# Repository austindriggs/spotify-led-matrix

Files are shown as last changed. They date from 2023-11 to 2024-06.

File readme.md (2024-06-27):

# Welcome to my first project!

My name is Austin Driggs and I am an Electrical Engineering student at WVU.
Please check out my [LinkedIn](https://www.linkedin.com/in/austindriggs/)!

### Purpose

This project uses an ESP32 microcontroller to display my "Now Playing" songs from Spotify onto an LED matrix panel, along with some added features.

The purpose of this project is to of course learn some new technical skills, but to also practice things related to my career in open sourced coding/projects and project management. I want to document everything along the way to cite sources from what I've learned, decisions I've made, and also to track time. 

## Important Information

### Project Epic

Please see the [Project Epic](https://github.com/austindriggs/spotify-led-matrix/issues/16) for a list of all issues and tasks completed and the order they were completed in.

### Hardware

The KiCAD project is for v7.

### Software

I plan to use python.

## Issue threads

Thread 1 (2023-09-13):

Pick out the display.

austindriggs, 2023-09-13:
## SUMMARY

I need to figure out how I want to display the album covers, or any additional info such as the song name and artist title.

## DEFINITION OF DONE

* [x] Research multiple options.
* [x] Decide upon the application.
* [x] Pick out best option for application.
* [x] Add to BOM.

## DESCRIPTION

This project originally spawned from my RGB LED Controller from my Quanex internship. This seemed a lot cooler and a step up.

### Some of the options include:
* LED Matrix
* Something similar to the [Car Thing](https://carthing.spotify.com/)
* An [LCD](https://www.circuitbasics.com/raspberry-pi-lcd-set-up-and-programming-in-python/) screen or similar.

### My chosen display:

I decided on using Adafruit's [64x64 RGB LED Matrix - 3mm Pitch - 192mm x 192mm](https://www.adafruit.com/product/4732) display. This is because I want it to be mostly just a decoration/display and not a player or [dashboard](https://youtu.be/A5A6ET64Oz8?si=J_fSCprO3xcJb7iC). I wanted a 3mm pitch because it is the biggest. I would also prefer to buy a knockoff version that's less of a cost.

## NOTES

Multiplexing seems relatively simple to understand and recreate. See [GreatScott's Video](https://youtu.be/uQMUPhyoXoE?si=eWbAlMCmC5SQ2RWF) for how it works, as well as his [shift register](https://youtu.be/Degt4HUzWXY?si=YdX082G8Zlpct4Gc) video.

### Notes from the website

#### Description

Winter time can be rough in the city. The sky is gray. The weather is unpredictable. So slough off those seasonal blues with some Times Square razzle dazzle from this sweet, ultra-high-density 64x64 RGB LED Matrix. These panels are typically used to make video walls. Here in New York we see them on the sides of buses and on top of taxi cabs displaying animations or video advertisements. We thought they looked really cool, so we picked up a few boxes of them from a factory. They have 4,096 bright RGB LEDs arranged in a 64x64 grid at a 3mm pitch.

WARNING! These 64-pixel tall matrices use a non-standard 5-address multiplexing system!

Many add-ons or drivers use only a 4-address (ABCD) setup. You can use these matricies with our [RGB Matrix Bonnet for Raspberry Pi](https://www.adafruit.com/product/3211), [RGB Matrix HAT](https://www.adafruit.com/product/2345) (you'll need to connect a solder jumper) or [Matrix Portal](https://www.adafruit.com/product/4745) (ditto, jumper required). Other libraries such as our Arduino shield with Adafruit library or our HDMI driver boards don't support 5-address multiplexing!

The [SmartLED Shield](https://www.adafruit.com/product/1902) in combination with the [Teensy 3.5/3.6](https://www.adafruit.com/product/3266) has the hardware for driving these 5-address panels, and enough RAM to refresh the 4096 pixels, however the power plug must be manually soldered/adapted because the shield overlaps it.

Full Kit Contents:

64x64 RGB panel
IDC ribbon cable (~16cm)
power cable (~50cm)

#### RAM & Processor Requirements

Keep in mind that these displays were designed to be driven by FPGAs or other high speed processors: they do not have built in PWM control of any kind. Instead, you're supposed to redraw the screen over and over to 'manually' PWM the whole thing.

You'll need about 1600 bytes of RAM to buffer the 12-bit color image. You cannot use this size panel with an Arduino UNO (ATmega328) or ATmega32u4 - you need a chip with more RAM! These displays are technically 'chainable' - connect one output to the next input - as long as you have the RAM and CPU to handle it

This display does best with a high speed, high RAM microcontroller like a SAMD21, SAMD51, ESP32, etc. 8-bit micros are going to struggle if they work at all. The good news is that the display is pre-white balanced with nice uniformity so if you turn on all the LEDs it's not a particularly tinted white.

#### Power Requirements

There's a lot of LEDs! You may need up to 4A per panel. [We suggest our 4A regulated 5V adapter](https://www.adafruit.com/products/1466) and then [connecting a 2.1mm jack](https://www.adafruit.com/products/368). Please check out our tutorials for more details!

#### Connection Requirements

These displays require 13 GPIO pins to control. You may have to use consecutive or special pins depending on the driver firmware. We'll be honest: folks who try to wire directly are usually not successful, its easy to get confused and misconnect. For that reason we strongly recommend a ready-to-go board or adapter that makes wiring as easy as plugging in the cables and powering with 5V

We recommend the [Matrix Portal ESP32-S3](https://www.adafruit.com/product/5778) for a WiFi-enabled powerful plug-and-play board
The original [Matrix Portal with SAMD51](https://www.adafruit.com/product/4745) is also a great plug-and-play board if you happen to want a Cortex M4 as a main processor (we recommend the S3 version, above, as it is faster and has more memory)
For many Arduino-shaped boards, [you may be able to use our RGB Matrix Shield](https://www.adafruit.com/product/2601) (check the product page and tutorial for which Arduino-like boards can be used)
We also have [RGB Matrix FeatherWings](https://www.adafruit.com/product/3036) for many Feather boards (check the product page and tutorial for which Feather boards can be used)
[For Raspberry Pi computers, our RGB Matrix Bonnet](https://www.adafruit.com/product/3211) is fully plug-and-play for powerful Linux-controlled displays.
We've also got [our great Protomatter library that works in Arduino and CircuitPython](https://learn.adafruit.com/adafruit-protomatter-rgb-matrix-library) for quick usage of many chained matrices.

Please note! These panels are remainder stock from factories that make huge light boards. For that reason, the look and size might vary from batch to batch, even though the basic operation, codebase and tutorial is the same.

Note: This does not include [4 mounting screws and mini-magnets, however we do have them available separate here](https://www.adafruit.com/product/4631)!

#### Technical Details
Brightness: 2800cd/square meter
Size: 192mm x 192mm
Pitch: 3M
5 Addressable Pins
Compatible with M3 mounting screws
Scan: 1/32
Refresh Frequency: >=400HZ
Waterproof Class: IP43
Weight: 235g (only matrix panel) / 269g (w/ components)
Best for indoor use

## SUPPORT

https://github.com/austindriggs/spotify-led-matrix/assets/112009203/72448174-78da-49d1-a2c1-c9317aefab7e

This is what I want to achieve.

First LED Matrix [video](https://youtu.be/vugulzS0EoU?si=8Op36dCSKbHJs5oa) I watched.

austindriggs, 2023-09-29:
Digikey: [4732](https://www.digikey.com/en/products/detail/adafruit-industries-llc/4732/13280266)

Closed 2023-09-13.

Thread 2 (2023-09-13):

Pick out the microcontroller

austindriggs, 2023-09-13:
## SUMMARY

Research and evaluate the different options for a microcontroller (or processor?). Also want to start thinking about the support given/needed for the controller.

## DEFINITION OF DONE

* [x] Research multiple options.
* [x] Pick out best option for application.

## DESCRIPTION

The controller will serve as the brains of the whole project.

### Some of the options include:
* Arduino
   * [The Collection](https://store-usa.arduino.cc/collections/boards)
   * [Arduino® Nano ESP32](https://store-usa.arduino.cc/collections/boards/products/nano-esp32)
   * [Arduino Uno Rev3](https://store-usa.arduino.cc/collections/boards/products/arduino-uno-rev3)
* ESP32
   * [From amazon: ESP32S ESP32 ESP-WROOM-32](https://a.co/d/ead8wBQ)
   * [Trinity](https://www.makerfabs.com/esp32-trinity.html)
   * [NodeMCU ESP32](https://esphome.io/devices/nodemcu_esp32.html): [Waveshare](https://www.waveshare.com/nodemcu-32s.htm)
   * [ESP32-DevKitC](https://www.espressif.com/en/products/devkits/esp32-devkitc) from ExpressIf (makers of the ESP32 chip).
   * [ExpressIf Development Boards](https://www.espressif.com/en/products/devkits)
   * [SparkFun ESP32 Thing](https://www.sparkfun.com/products/13907)
   * [Adafruit Matrix Portal S3 CircuitPython Powered Internet Display](https://www.adafruit.com/product/5778) recommended by Adafruit
* Raspberry Pi
   * [Pico](https://www.raspberrypi.com/documentation/microcontrollers/raspberry-pi-pico.html)
* Other:
   * STM32: [STM32 Nucleo-32 development board with STM32F303K8 MCU](https://www.st.com/en/evaluation-tools/nucleo-f303k8.html) from Eric
   * Adafruit recommends the [SmartLED Shield](https://www.adafruit.com/product/1902) in combination with the [Teensy 3.5/3.6](https://www.adafruit.com/product/3266)

I did not expect so many options. In my mind there were 3 options: Arduino Nano, ESP32, or the Pi Pico, and I thought there were only one or two development boards for each. It turns out, there's anything you could imagine.

### My chosen controller:

After a LOT of research and evaluation, I decided upon two different options. Both of these use the ESP32 Chip.

#### Why the ESP32?

The biggest reason that I chose the ESP32 is its the second microcontroller I've heard/learned about (after Arduinos), and it has WiFi which I'll need to connect to my Spotify account. It also has all of the features and then some that I could want for this project.

#### 1. ESP32 Dev Board from ExpressIf

This would be the simplest and fastest option. There are a lot of dev boards for the ESP32 but I figured it would be best to use a popular one from ExpressIf, the creators of the ESP32 chip. The dev board would plug right into my PCB that then plugs into the LED Display.

#### 2. Creating my own "dev board" using the ESP32 chip

This wouldn't be too simple or fast, but it would be the most fun, and incorporate more EE and CpE into this project. I might as well design a "dev board" onto the PCB instead of just plugging someone else's into it. I still would go with the ESP32 because its a very popular option with a lot of support (if I need it), and is pretty cheap.

The ultimate design will be linked to this issue or in the comments once decided.

## NOTES

My plan is to create a breakout board that has all of the features #3 that I want on it, that plugs into the back of the LED matrix.

## SUPPORT

* [What’s difference between Microcontroller (µC) and Microprocessor (µP)?](https://www.geeksforgeeks.org/whats-difference-between-microcontoller-%C2%B5c-and-microprocessor-%C2%B5p/)

### Resources for ESP32

1. [How to add WiFi Control to any project || ESP32 Beginner's Guide](https://youtu.be/ZAqNKaX3LQ0?si=C86ynU-mN9dbjzc3) by GreatScott!
   * This was the first video I watched that introduced me to the ESP32.
3. All about ESP32: [The Internet of Things with ESP32](http://esp32.net/)
   * This website probably has anything and everything you could ever need to know about the ESP32.
4. [Overview of ESP32 features. What do they practically mean?](https://www.exploreembedded.com/wiki/Overview_of_ESP32_features._What_do_they_practically_mean%3F)
   * A good overview of the ESP32 and some of its features.

### Resources for STM32

1. User Manual: Getting Started [UM1727](https://www.st.com/resource/en/user_manual/um1727-getting-started-with-stm32-nucleo-board-software-development-tools-stmicroelectronics.pdf)
   * Supported by IDEs with C/C++ compilers and debuggers
2. User Manual [UM1596](https://www.st.com/resource/en/user_manual/um1956-stm32-nucleo32-boards-mb1180-stmicroelectronics.pdf)
3. [STM32 vs. ESP32: Which is Better?](https://electronicshacks.com/stm32-vs-esp32/)
   * STM32 lacks WiFi.

austindriggs, 2023-09-29:
I am going to prototype with the ESP32 dev board [todo]() using a breadboard and then use the ESP32 chip [todo]() to create a final design on a PCB.

austindriggs, 2023-10-18:
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

Closed 2023-09-26.

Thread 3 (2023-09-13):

Pick out the hardware features

austindriggs, 2023-09-13:
## SUMMARY

The display is going to need some additional hardware to go along with the display and controller.

## DEFINITION OF DONE

* [x] Create a list of features
* [x] Evaluate them
* [x] Determine the hardware needed.

## DESCRIPTION

I want some additional features provided by some extra hardware.

### Desired Features

1. Display
2. Dev Board or equivalent
3. On/Off switch (night sensor?)
4. Brightness and Volume Control
   * The display will not be a speaker, it will just control the volume on my phone or speaker.
5. Configuration Options
   * Used to switch between modes: Album Covers
      * Now Playing
      * Liked songs
      * Top 100 songs
      * My playlist pictures/cover
   * I want to be able to edit these configurations and add some later if I want more. Right now planning on having 4-8 buttons that you can click to determine the mode; also could look into other options (rotary encoder?).
   * Other modes to consider:
      * Clock mode
      * Something to do with soccer? Show current scores of games.
6. Physical/Mechanical
   * 3D printed mount/case to make it look professional
   * Diffuser to look cleaner
   * Dry erase tape next to config buttons

### Required Hardware

First Schematic:

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

I used this to better visualize some of the things I want, and to actually have a first design.

IEEE at WVU will buy the parts, I'm just not sure what the vendor will be. Creating the BOM will be in a future issue.

General:
- Display
- ESP32 Dev Board (used for prototyping)
- ESP32 Chip and support (decided in later issue)

Power:
- 5V Power Supply
- On/Off Switch
- 3.3V Regulator and supporting components

Connectors:
- Barrel Connector for power supply
- Power Connector for LED Matrix
- DIO Connector for LED Matrix

Brightness and Volume Control:
- Brightness Slider Pot
- Volume Rotary Encoder

Configuration Modes:
- Buttons
- Pull Down Resistors

Physical/Mechanical:
- 3D Printed Case
- Diffuser
- Dry Erase Tape

## NOTES

I decided on a rotary encoder instead of a pot because I want the default volume to come from the phone and/or the last setting, not from the current setting of the pot. Using a rotary encoder will allow the PCB/controller to **change** the volume, not **set** it from whatever resistance the pot is at when the display is turned on.

## SUPPORT

A lot of these were up to personal preference so I didn't have a lot of sources to cite.

- [LED Matrix Diffuser](https://learn.adafruit.com/adafruit-matrixportal-m4/led-matrix-diffuser) by M. LeBlanc-Williams on Adafruit

Rotary Encoder:

- [What is Rotary Encoder? Types, Principle, working in detail](https://www.circuitschools.com/what-is-rotary-encoder-types-principle-working-in-detail/) from Circuit Schools
- [How to use rotary encoders](https://youtu.be/9j-y6XlaE80?si=IYo4ydTkM3pU-6Cg) by FriendlyWire
- [STEREO VOLUME AND BALANCE CONTROL WITH ROTARY ENCODER USING MAX5440](https://www.buildcircuit.com/stereo-volume-and-balance-control-with-rotary-encoder-using-max5440/) from Build Circuit

austindriggs, 2023-11-23:
## UPDATE FOR FINAL DESIGN

#### Config Options

The configuration options and volume/brightness control will all be determined through a switch rotary encoder. This is because I don't know exactly how many different modes I want and this will come out cleaner looking. I would rather have buttons just for fun, but I think the rotary encoder circuit is a better design.

#### On/Off Switch

I decided on no on/off switch because I want the ESP32 to always be on and checking whether or not something is playing. If I change my mind later, they sell the power supplies with switches between the wall plug in and the barrel connector.

#### LEDs

I want some LEDs to show what mode you are in since you can't press buttons to determine the mode. I don't want a power LED because I don't want it to always be on, distracting from the display. I would also like a general development LED.

#### Diffuser

I still plan to have a diffuser for the display. I'll also be adding an acrylic cover over the PCB to look nice and professional. I'm planning to either have a 3D printed or wood cutout frame to go around the PCB and display.

austindriggs, 2023-11-23:
Inspiration for acrylic PCB cover: [DE10-Lite](https://www.terasic.com.tw/cgi-bin/page/archive.pl?Language=English&No=1021) from CPE271 Lab

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

austindriggs, 2023-11-23:
## Physical Sketch

TODO

austindriggs, 2023-11-23:
## Spotify Code

You can put images on silkscreen somehow.

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

Closed 2023-10-01.

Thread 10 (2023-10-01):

Design the ESP32 circuit

austindriggs, 2023-10-01:
## SUMMARY

I want to design my own circuit using the ESP32 and implement it into my project instead of using a premade dev board that someone else designed and built. I could have easily used a dev board or the recommended boards but I wanted this project to have an EE component to it and this lets me have some more fun with and learn more from the project.

## DEFINITION OF DONE

* [x] Planning stages
* [x] Construct the recommended circuit for my module
* [x] Make any changes for my implementation
* [x] Review and implement

## DESCRIPTION

### Planning

I researched a lot and listed all sources below.

### Implementation

I will be using the ESP32-WROOM-32E SoC which has the ESP32-D0DWD-V3 module. Here is the [datasheet](https://www.espressif.com/sites/default/files/documentation/esp32-wroom-32e_esp32-wroom-32ue_datasheet_en.pdf).

#### Peripherals

The chip runs on 3.3V and will need decoupling capacitors on the input. Decoupling capacitors of smaller value should be placed closer to the input of the chip.  It can draw up to 500mA of current.

The power also goes through a 10k resistor and 1uF capacitor into the enable pin to create a 1ms delay for the chip to turn on.

The chip also connects to the programming circuit #12

#### Inputs

All of the inputs come from the rotary encoder circuit designed in #11

#### Outputs

All of the outputs connect to the LEDs designed in #13

#### Display

The display pins are as follows from the [PxMatrix](https://github.com/2dom/PxMatrix) library:
- Chip select pins: A = 19, B = 23, C = 18, D = 5, E = 15
 - LAT = 16, OE = 14, CLK = 14
 - R1 = 13

Where are the rest of the RGB inputs? "R1" internally connects (on the display) to "R1 OUT", and the same goes for every input. This means that we can connect "R1 OUT" to "R2", "R2 OUT" to "G1", and so on. This is so we can have one data line and use SPI to drive the display.

### Circuit Design

#### ESP32 Module

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

#### Display Connectors

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

## NOTES

None

## SUPPORT

### Datasheets

- [ESP32 Series](https://www.espressif.com/sites/default/files/documentation/esp32_datasheet_en.pdf)
- [ESP32­WROOM­32E](https://www.espressif.com/sites/default/files/documentation/esp32-wroom-32e_esp32-wroom-32ue_datasheet_en.pdf)
- [ESP32 Hardware Design Guidelines](https://www.espressif.com/sites/default/files/documentation/esp32_hardware_design_guidelines_en.pdf)

### ESP32

- Espressif ESP32 [Development Boards](https://www.espressif.com/en/products/devkits)
- [ESP32-DevKitC V4 Getting Started Guide](https://docs.espressif.com/projects/esp-idf/en/latest/esp32/hw-reference/esp32/get-started-devkitc.html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)
- [ESP32 Pinout Reference](https://lastminuteengineers.com/esp32-pinout-reference/)
- [How to Make Custom ESP32 Board in 3 Hours | Full Tutorial](https://youtu.be/S_p0YV-JlfU?si=LE2YEZPvd23FqILa) by Robert Feranec
- [Minimalist Microcontroller: Building a Bare-Bones Dev Board](https://youtu.be/tQ0dL_9M1wI?si=0l7a1ve4iu3fDDgh) by atomic14
- [ESP32-Trinity](https://github.com/witnessmenow/ESP32-Trinity) board's GitHub by Brian Lough

### Additional Resources

- [Decoupling (Bypass) Capacitors](https://learn.sparkfun.com/tutorials/capacitors/application-examples#decoupling)
- [Placing of capacitor close to IC power pin](https://electronics.stackexchange.com/questions/639189/placing-of-capacitor-close-to-ic-power-pin-logic)
- [What are Communication Protocols & Their Working](https://www.elprocus.com/communication-protocols/)
- [SPI: The serial peripheral interface](https://youtu.be/MCi7dCBhVpQ?si=Q8dxGS0spwcLy3N3) by Ben Eater
- [Electronic Basics #19: I2C and how to use it](https://youtu.be/_fgWQ3TIhyE?si=USyTOtSFQCMEOFrR) by GreatScott!
- [Electronic Basics #36: SPI and how to use it](https://youtu.be/fvOAbDMzoks?si=XtatI0WNUG0Wzbd8) by GreatScott!

### Supporting Images

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

"5 Module Schematic" (page 22)

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

"6 Peripheral Schematics" (page 24)

austindriggs, 2023-11-23:
## Final Design

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

austindriggs, 2023-11-24:
[ESP32-DevKitC-V4_SCH_20180607A.pdf](https://github.com/austindriggs/spotify-led-matrix/files/13453996/ESP32-DevKitC-V4_SCH_20180607A.pdf)

austindriggs, 2023-11-24:
[ESP32-DevKitC-V4_PCB_20171206A.pdf](https://github.com/austindriggs/spotify-led-matrix/files/13453999/ESP32-DevKitC-V4_PCB_20171206A.pdf)

austindriggs, 2023-11-29:
#### Changing DISPLAY_OUT Connector:

TODO

austindriggs, 2024-02-01:
Closed as circuit is complete: Any test circuit using the dev board will (*probably not*) be documented somewhere else

Closed 2024-02-01.

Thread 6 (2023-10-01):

Create the BOM

austindriggs, 2023-10-01:
## SUMMARY

Summarize the issue in 1-3 sentences.

## DEFINITION OF DONE

* [ ] List the tasks that need completed.

## DESCRIPTION

Describe the general work completed and why the tasks were performed.

## NOTES

Put any additional notes here; mostly what was learned.

## SUPPORT

List any resources or supporting images here.

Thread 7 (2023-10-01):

Design the circuit schematic.

austindriggs, 2023-10-01:
## SUMMARY

Summarize the issue in 1-3 sentences.

## DEFINITION OF DONE

* [ ] List the tasks that need completed.

## DESCRIPTION

Describe the general work completed and why the tasks were performed.

## NOTES

Put any additional notes here; mostly what was learned.

## SUPPORT

List any resources or supporting images here.

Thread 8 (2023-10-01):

Design the circuit schematic

austindriggs, 2023-10-01:
## SUMMARY

Summarize the issue in 1-3 sentences.

## DEFINITION OF DONE

* [ ] List the tasks that need completed.

## DESCRIPTION

Describe the general work completed and why the tasks were performed.

## NOTES

Put any additional notes here; mostly what was learned.

## SUPPORT

List any resources or supporting images here.

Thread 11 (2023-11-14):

Design the rotary encoder circuit

austindriggs, 2023-11-14:
## SUMMARY

The rotary encoder will serve as the user's input to determine how the display operates.

## DEFINITION OF DONE

* [x] Research rotary encoders.
* [x] Design the circuit

## DESCRIPTION

As mentioned in a previous issue, a rotary encoder is used because I want to be able to change states without being in a preset one. A potentiometer would have a preset resistance and only go so far up and down; a rotary encoder can be preset to anything and go as far needed up or down.

The circuit is pretty simple to understand and design, it's just repeated three times for each pin.

#### Pins

The switch and A and B pins are connected to ground when pressed or when the encoder is turned.

#### Debounce Circuit

Eric mentioned to me that buttons aren't perfect electrical connections when pressed. This causes a ripple effect in the signal and can result in the microcontroller reading "bouncing". This exact circuit might be a little overkill, but it was cool to learn about and design. I enjoy seeing how simple components can replace an IC.

#### Level Shifters

The rotary encoder is connected to +5V and needs to be input to the 3V3 microcontroller. These level shifters are used to preserve the signal as best as possible from the debounce circuit. Could I have used a simple voltage divider? Could I have used a simple IC? Probably, but again, I wanted to learn about and implement this.

### Circuit Design

Rotary Encoder

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

## NOTES

Digikey links:
- Rotary Encoder: [ACZ11BR1E-20FD1-12C](https://www.digikey.com/en/products/detail/cui-devices/ACZ11BR1E-20FD1-12C/1923355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)
- The rest of the components will be picked out later as they aren't as big of a deal for the design. See #6.

Recommended filtering circuit design:

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

## SUPPORT

#### Rotary Encoder
- [What is Rotary Encoder?](https://www.circuitschools.com/what-is-rotary-encoder-types-principle-working-in-detail/)

#### Debounce
- [Ultimate Guide to Switch Debounce](https://www.eejournal.com/article/ultimate-guide-to-switch-debounce-part-3/): Step by step visuals
- [What is Switch Bouncing and How to prevent it using Debounce Circuit](https://circuitdigest.com/electronic-circuits/what-is-switch-bouncing-and-how-to-prevent-it-using-debounce-circuit): Has the design I went with
- [What is Schmitt Trigger](https://www.electrical4u.com/schmitt-trigger/)
- [Schmitt Trigger: What is it And How Does it Work? (Inverting & Non-Inverting Circuit Diagrams)](https://www.electrical4u.com/schmitt-trigger/)

#### Level Shifters
- [5V encoder output to 3.3V microcontroller](https://electronics.stackexchange.com/questions/606164/5v-encoder-output-to-3-3v-microcontroller)

Closed 2023-11-24.

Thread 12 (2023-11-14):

Design the programming USB to UART circuit

austindriggs, 2023-11-14:
## SUMMARY

The ESP32 needs to be able to communicate with my laptop.

## DEFINITION OF DONE

* [x] Research USB and UART
* [x] Design the circuit
* [x] Review and make improvements

## DESCRIPTION

### USB and UART

Going into this project I had no idea how my laptop communicated with a microcontroller, or even any USB devices.

I'm using a USB C connector just because that seems to be the trend with ESP32's.

#### Changes made for my design:

I researched the recommended USB to UART converter and found out that it had some issues with it. At work Dave found a "Basic USB to UART" converter that looks better than the old one. I decided to go with a similar and popular one on digikey linked below.

I added a DNP resistor between the USB shield and GND because connecting the USB shield directly to GND can sometimes cause problems (if the two don't exactly "agree" on what GND is).

I removed the 0 ohm resistors in the EN and BOOT buttons and added serial termination circuits to the input on the ESP32 because it can be helpful to "minimize reflections and improve the quality of the signal because it is split in two places".

I decided that I don't need the JTAG connector for debugging anything.

### Circuit Design

USB to UART

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

Programming

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

Note: There is an LED connected to VBUS just to show it's plugged in.

## NOTES

Digikey Links:
- Converter: [FT231XS-R](https://www.digikey.com/en/products/detail/ftdi-future-technology-devices-international-ltd/FT231XS-R/3029139)
- USB Connector: [2169900003](https://www.digikey.com/en/products/detail/molex/2169900003/13913753?s=N4IgTCBcDa4IwDYCcSAM7UGYQF0C%2BQA)
- The rest of the components will be picked out later as they aren't as big of a deal for the design. See #6.

## SUPPORT

#### Introductory Sources:
- [How does USB device discovery work?](https://youtu.be/wdgULBpRoXk?si=wOfGjkn2jC6Lxow7) by Ben Eater
- [How does a USB keyboard work?](https://youtu.be/wdgULBpRoXk?si=42Qrpx2trIPqQYAu) by Ben Eater
- [PROTOCOLS: UART - I2C - SPI - Serial communications #001](https://www.youtube.com/hashtag/001) by Electronoobs: First video I watched about all this and very helpful in understanding basic differences between everything.

#### All others:
- [Why does ESP DevKit have 0Ω resistors for the TX and RX?](https://electronics.stackexchange.com/questions/601856/why-does-esp-devkit-have-0%ce%a9-resistors-for-the-tx-and-rx)
- [Damping and Reflection Transfer with a Series Termination Resistor | Blog | Altium Designer](https://resources.altium.com/p/damping-and-reflection-transfer-series-termination-resistor)
- [When and Why to use termination resistors?](https://forum.allaboutcircuits.com/threads/when-and-why-to-use-termination-resistors-please.127453/)
- [USB Shield. To ground or not to ground?](https://electronics.stackexchange.com/questions/389972/usb-shield-to-ground-or-not-to-ground)
- [Where does 9600 bps come from?](https://www.sparkfun.com/news/2231)
- [Here is why USB Type-C is AWESOME and how you can use Power Delivery for your electronics!](https://youtu.be/W13HNsoHj7A?si=490IWMKXnSZZBZnq) by GreatScott!
- [Parallel Termination Basics - Phil's Lab #119](https://www.youtube.com/hashtag/119) by Phil's Lab (Part 1, didn't use parallel termination in my design)
- [Series Termination Basics - Phil's Lab #121](https://www.youtube.com/hashtag/121) by Phil's Lab (Part 2)

austindriggs, 2024-02-01:
Adding a DNP serial connector just in case for good practice and because I have the room:

TODO

Closed 2024-02-01.

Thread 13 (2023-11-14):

Design everything else in the schematic

austindriggs, 2023-11-14:
## SUMMARY

Summarize the issue in 1-3 sentences.

## DEFINITION OF DONE

* [x] Research anything else I need for my circuit
* [x] Design those circuits

## DESCRIPTION

There isn't a whole lot that I'm missing in my circuit design.

#### Power

The power circuit is pretty simple. I am going to use a standard barrel jack connector to provide 5V with 6-8A. The display will draw up to 4A. The voltage regulator outputs 3.3V to the microcontroller which will draw up to 500mA.

#### LEDs

I want some LEDs to determine what mode I am in as well as just a general development LED to use whenever I want/need it. I also threw in a USB LED to show when I'm connected to USB. The transistors are there to drive the LEDs.

### General Components
Standard resistor values
Why MOSFET
Standard cap values

### Circuit Design

Power

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

LEDs

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

## NOTES

Digikey links:
- All of the components will be picked out later as they aren't as big of a deal for the design. See #6.

## SUPPORT

None

austindriggs, 2024-02-01:
Changing the 3V3 regulator design in #20

Closed 2024-02-01.

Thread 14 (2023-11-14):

Spotify LED Matrix Epic

austindriggs, 2023-11-14:
## SUMMARY

Summarize the issue in 1-3 sentences.

## DEFINITION OF DONE

### Order of issues:

* [ ] #1 Pick out the display
* [ ] #2 Pick out the microcontroller
* [ ] #3 Pick out the hardware features
* Design the schematic
* [ ] #10 Design the ESP32 Circuit
* [ ] #12 Design the programming USB to UART circuit
* [ ] #11 Design the rotary encoder circuit
* [ ] #13 Design everything else in the schematic

## DESCRIPTION

Describe the general work completed and why the tasks were performed.

## NOTES

Put any additional notes here.

## SUPPORT

List any resources or supporting images here.

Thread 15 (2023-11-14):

Review the schematic

austindriggs, 2023-11-14:
## SUMMARY

Summarize the issue in 1-3 sentences.

## DEFINITION OF DONE

* [ ] Review
* [ ] Make necessary changes
* [ ] Note why

## DESCRIPTION

Describe the general work completed and why the tasks were performed.

## NOTES

Put any additional notes here.

## SUPPORT

List any resources or supporting images here.

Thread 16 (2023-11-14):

PROJECT EPIC

austindriggs, 2023-11-14:
## SUMMARY

Summarize the issue in 1-3 sentences.

## DEFINITION OF DONE

### Order of issues:
* Planning stages:
* [ ] #1
* [ ] #2
* [ ] #3
* Design the schematic:
* [ ] #10
* [ ] #12
* [ ] #11
* [ ] #13
* [ ] #15
* [ ] TODO

## DESCRIPTION

Describe the general work completed and why the tasks were performed.

## NOTES

Put any additional notes here.

## SUPPORT

List any resources or supporting images here.

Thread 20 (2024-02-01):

Swap the linear regulator for a switching power supply

austindriggs, 2024-02-01:
## SUMMARY

Just realized I picked out a linear LDO voltage regulator (this is what Espressif uses in their dev board) and I don't want that.

## DEFINITION OF DONE

- [ ] Document differences
- [ ] Pick out and design a replacement
- [ ] Swap it out and document changes

## DESCRIPTION

I didn't really know any better at first and just chose the same (ish) power supply that Espressif used in their design. I'm guessing they used a LDO linear regulator because their dev board is tight and compact and the switching could cause some noise. I really don't have to worry about this, as my components are all spread out, so I'd be better off using a switching regulator.

After learning more about them both, I watched a video by EEVblog where he HIGHLY recommended a popular design, the [MC34063}(https://www.onsemi.com/pdf/datasheet/mc34063a-d.pdf)

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

I thought it would be fun to use this, as its been around for decades (its older than me), its popular and can be used for a ton of different applications, and I think it would be fun to design my own and go through all the calculations needed.

### Typical Step-Down Converter

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

## NOTES

todo

## SUPPORT

- Watched first: [EEVblog #90 - Linear and LDO regulators and Switch Mode Power Supply Tutorial](https://youtu.be/cM7t1Mpu7s4?si=X2t8tjF7_mOB6S6u) by [EEVblog](https://www.youtube.com/@EEVblog)
- Then: [EEVblog #110 - Let's Design a DC to DC Switchmode Converter](https://youtu.be/qGp82xhybs4?si=M-Juoj0jWAPET9-P) by [EEVblog](https://www.youtube.com/@EEVblog)
- [DIY Buck Converter || How to step down DC voltage efficiently](https://www.youtube.com/watch?v=m8rK9gU30v4) by [GreatScott!]((https://www.youtube.com/@GreatScott!)

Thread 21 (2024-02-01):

Create the BOM

austindriggs, 2024-02-01:
## SUMMARY

Create the BOM

## DEFINITION OF DONE

- [ ] PCB (stencil?)
- [ ] Components
- [ ] LED Matrix
- [ ] Test components
- [ ] Rotary encoder knob
- [ ] Acrylic?
- [ ] Any test equipment
- [ ] Solder paste?
- [ ] Screws?

## DESCRIPTION

todo

## NOTES

todo

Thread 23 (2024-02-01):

Ignore: Issue for keeping track of First2 time

austindriggs, 2024-02-01:
## August 2023

Date: | Time In: | Time Out: | Hours: | Activity: | Notes:
-- | -- | -- | -- | -- | --
1-Aug |   |   | 0.00 |   |  
2-Aug |   |   | 0.00 |   |  
3-Aug |   |   | 0.00 |   |  
4-Aug |   |   | 0.00 |   |  
5-Aug |   |   | 0.00 |   |  
6-Aug |   |   | 0.00 |   |  
7-Aug |   |   | 0.00 |   |  
8-Aug |   |   | 0.00 |   |  
9-Aug |   |   | 0.00 |   |  
10-Aug |   |   | 0.00 |   |  
11-Aug |   |   | 0.00 |   |  
12-Aug |   |   | 0.00 |   |  
13-Aug |   |   | 0.00 |   |  
14-Aug |   |   | 0.00 |   |  
15-Aug |   |   | 0.00 |   |  
16-Aug |   |   | 0.00 |   |  
17-Aug |   |   | 0.00 |   |  
18-Aug |   |   | 0.00 |   |  
19-Aug |   |   | 0.00 |   |  
20-Aug |   |   | 0.00 |   |  
21-Aug | 7:00:00 PM | 8:00:00 PM | 1.00 | Club Meetings/Activities | Ice cream social / first meeting
22-Aug |   |   | 0.00 |   |  
23-Aug | 5:00:00 PM | 6:00:00 PM | 1.00 | Club Meetings/Activities | Continued development on the breakout board I designed that's used to test our laser's power supply
24-Aug | 5:00:00 PM | 6:00:00 PM | 1.00 | Research | Finished initial testing; board works good.
25-Aug | 5:00:00 PM | 6:00:00 PM | 1.00 | Research | Updated and implemented code to streamline automated testing.
26-Aug |   |   | 0.00 |   |  
27-Aug |   |   | 0.00 |   |  
28-Aug | 7:00 PM | 8:00 PM | 1.00 | Club Meetings/Activities | First official meeting
29-Aug |   |   | 0.00 |   |  
30-Aug | 5:00:00 PM | 6:00:00 PM | 1.00 | Research | Performed and Updated IMU (Inertial Measurement Unit) Acceptance Testing -> Also worked on Ethernet testing.
31-Aug | 5:00:00 PM | 6:00:00 PM | 1.00 | Research | Initial format update to Laser Acceptance Testing
  |   |   | 0.00 |   |  
  |   |   | 0.00 |   |  
  |   |   | 0.00 |   |  
  |   |   | 0.00 |   |  
  |   |   | 0.00 |   |  
  |   |   | 0.00 |   |  
  |   |   | 0.00 |   |  
  |   |   | 0.00 |   |  
  |   |   | 0.00 |   |  
  |   |   | 0.00 |   |  
  |   |   | 0.00 |   |  
  |   |   | 0.00 |   |  
  |   |   | 0.00 |   |  
  |   |   | 0.00 |   |  
  |   |   | 0.00 |   |  
  |   | Total: | 7.00 |   |  

## September 2023

Date: | Time In: | Time Out: | Hours: | Activity: | Notes:
-- | -- | -- | -- | -- | --
1-Sep | 5:00:00 PM | 6:00:00 PM | 1.00 | Research | Continued and finished laser acceptance testing. Worked on Ethernet testing for IMU.
2-Sep |   |   |   |   |  
3-Sep | 1:00:00 PM | 2:15:00 PM | 1.25 | Other (Describe in Notes) | Prepared resume for career fair on 9/14Updated LinkedIn and Handshake
4-Sep |   |   | 0.00 |   |  
5-Sep | 4:30:00 AM | 6:30:00 AM | 2.00 | Giving Tutoring | PHYS 101 Tutoring
6-Sep |   |   | 0.00 |   |  
7-Sep |   |   | 0.00 |   |  
8-Sep |   |   | 0.00 |   |  
9-Sep |   |   | 0.00 |   |  
10-Sep |   |   | 0.00 |   |  
11-Sep | 6:45:00 AM | 7:45:00 AM | 1.00 | Club Meetings/Activities | Meeting
12-Sep | 8:30:00 AM | 9:45:00 AM | 1.25 | Special Project (Describe in Notes) | Started initial development of the LED Matrix Display. Researched and picked out a display, and am starting on researching microcontrollers now. Documented everything on GitHub for open-sourced community.
13-Sep |   |   | 0.00 |   |  
14-Sep |   |   | 0.00 |   |  
15-Sep |   |   | 0.00 |   |  
16-Sep |   |   | 0.00 |   |  
17-Sep | 7:30:00 PM | 9:00:00 PM | 1.50 | Club Meetings/Activities | All students #2
18-Sep |   |   | 0.00 |   |  
19-Sep | 4:30:00 AM | 6:30:00 AM | 2.00 | Giving Tutoring | PHYS 101 Tutoring
20-Sep |   |   | 0.00 |   |  
21-Sep |   |   | 0.00 |   |  
22-Sep |   |   | 0.00 |   |  
23-Sep |   |   | 0.00 |   |  
24-Sep | 3:45:00 PM | 5:00:00 PM | 1.25 | Special Project (Describe in Notes) | Continued research into microcontrollers as well as a general design for the features.
25-Sep | 5:30 PM | 6:30:00 PM | 1.00 | Giving Tutoring | PHYS 101
25-Sep | 7:00 PM | 8:00 PM | 1.00 | Club Meetings/Activities | Meeting
26-Sep |   |   | 0.00 |   |  
27-Sep |   |   | 0.00 |   |  
28-Sep |   |   | 0.00 |   |  
29-Sep |   |   | 0.00 |   |  
30-Sep | 6:00:00 PM | 7:30:00 PM | 1.50 | Special Project (Describe in Notes) | Finalized the general design and features. Decided on the ESP32 and thinking about creating my own "dev board" instead of using someone elses. Designed a lot of the "features" part of the circuit.
  |   |   | 0.00 |   |  
  |   |   | 0.00 |   |  
  |   |   | 0.00 |   |  
  |   |   | 0.00 |   |  
  |   |   | 0.00 |   |  
  |   |   | 0.00 |   |  
  |   |   | 0.00 |   |  
  |   |   | 0.00 |   |  
  |   |   | 0.00 |   |  
  |   |   | 0.00 |   |  
  |   |   | 0.00 |   |  
  |   |   | 0.00 |   |  
  |   |   | 0.00 |   |  
  |   |   | 0.00 |   |  
  |   |   | 0.00 |   |  
  |   |   | 0.00 |   |  
  |   | Total: | 14.75 |   |  

## October 2023

Date: | Time In: | Time Out: | Hours: | Activity: | Notes:
-- | -- | -- | -- | -- | --
1-Oct | 6:00:00 PM | 8:15:00 PM | 2.25 | Research | Researched the different ESP32 modules and their different features. Started the circuit design for the module I picked out and created the symbol for it in KiCad.
2-Oct |   |   | 0.00 |   |  
3-Oct | 8:00 PM | 8:45:00 PM | 0.75 | Special Project (Describe in Notes) | Worked on the circuit some more. Documented everything I was missing in GitHub and uploaded what I have so far for the circuit.
4-Oct |   |   | 0.00 |   |  
5-Oct |   |   | 0.00 |   |  
6-Oct |   |   | 0.00 |   |  
7-Oct | 10:00:00 AM | 11:30:00 AM | 1.50 | Special Project (Describe in Notes) | Determined and addded the peripherals needed for the ESP32 circuit.
8-Oct |   |   | 0.00 |   |  
9-Oct | 7:00 PM | 8:00 PM | 1.00 | Club Meetings/Activities | Meeting
10-Oct |   |   | 0.00 |   |  
11-Oct |   |   | 0.00 |   |  
12-Oct |   |   | 0.00 |   |  
13-Oct |   |   | 0.00 |   |  
14-Oct | 9:00:00 PM | 9:45:00 PM | 0.75 | Special Project (Describe in Notes) | Replaced buttons with only the rotary encoder and the support needed for it.
15-Oct | 2:00:00 PM | 3:00:00 PM | 1.00 | Special Project (Describe in Notes) | Researched and added debounce circuit for rotary encoder switch.
16-Oct |   |   | 0.00 |   |  
17-Oct |   |   | 0.00 |   |  
18-Oct |   |   | 0.00 |   |  
19-Oct | 8:30:00 PM | 9:45:00 PM | 1.25 | Special Project (Describe in Notes) | Researched and added level shifter for the rotary encoder output, leds to determine the select option, and cleaned up/minimized the schematic
20-Oct |   |   | 0.00 |   |  
21-Oct | 10:30:00 AM | 12:00:00 PM | 1.50 | Special Project (Describe in Notes) | Learned how to communicate with the controller from my laptop: Picked and added USB to UART converter and its support.
22-Oct | 9:00:00 PM | 9:45:00 PM | 0.75 | Special Project (Describe in Notes) | I found some notes for the USB to UART converter I picked (that was recommended). Did some research on it, and need to fix this just in case and put in the DNP components
23-Oct |   |   | 0.00 |   |  
24-Oct |   |   | 0.00 |   |  
25-Oct |   |   | 0.00 |   |  
26-Oct |   |   | 0.00 |   |  
27-Oct |   |   | 0.00 |   |  
28-Oct |   |   | 0.00 |   |  
29-Oct |   |   | 0.00 |   |  
30-Oct | 6:45:00 PM | 7:45:00 PM | 1.00 | Club Meetings/Activities | Meeting
31-Oct | 4:30 PM | 5:15:00 PM | 0.75 | Special Project (Describe in Notes) | Decided on not using the recommended USB to UART converter and researched some others as well as USB connectors
  |   |   | 0.00 |   |  
  |   |   | 0.00 |   |  
  |   |   | 0.00 |   |  
  |   |   | 0.00 |   |  
  |   |   | 0.00 |   |  
  |   |   | 0.00 |   |  
  |   |   | 0.00 |   |  
  |   |   | 0.00 |   |  
  |   |   | 0.00 |   |  
  |   |   | 0.00 |   |  
  |   |   | 0.00 |   |  
  |   |   | 0.00 |   |  
  |   |   | 0.00 |   |  
  |   |   | 0.00 |   |  
  |   |   | 0.00 |   |  
  |   | Total: | 12.50 |   |  

## November 2023

Date: | Time In: | Time Out: | Hours: | Activity: | Notes:
-- | -- | -- | -- | -- | --
1-Nov |   |   | 0.00 |   |  
2-Nov |   |   | 0.00 |   |  
3-Nov |   |   | 0.00 |   |  
4-Nov |   |   | 0.00 |   |  
5-Nov |   |   | 0.00 |   |  
6-Nov |   |   | 0.00 |   |  
7-Nov |   |   | 0.00 |   |  
8-Nov |   |   | 0.00 |   |  
9-Nov | 10:00:00 PM | 10:30:00 PM | 0.50 | Special Project (Describe in Notes) | Cleaned up schematic to look like Eric's
10-Nov | 8:00:00 PM | 9:15:00 PM | 1.25 | Special Project (Describe in Notes) | Designed USB to UART circuit and picked out components for it.
11-Nov | 1:45:00 PM | 2:15:00 PM | 0.50 | Special Project (Describe in Notes) | Researched and added series termination circuit for BOOT and EN circuits.
12-Nov | 8:00:00 PM | 10:45:00 PM | 2.75 | Special Project (Describe in Notes) | Changed and added my own level shifters. Picked out most (all except 0's) resistors, and some other components.
13-Nov | 9:45:00 AM | 11:00:00 AM | 1.25 | Special Project (Describe in Notes) | Added comments to entire schematic and reorganized it to make more sense.
13-Nov | 7:00:00 PM | 8:00:00 PM | 1.00 | Club Meetings/Activities | Meeting
14-Nov | 8:00:00 PM | 11:30:00 PM | 3.50 | Special Project (Describe in Notes) | Finished schematic and picked out most components! Updated Github format (added all tasks up to this point, just need to fill them in and describe them). Now ready to pick out the rest of the components and for review
15-Nov |   |   | 0.00 |   |  
16-Nov |   |   | 0.00 |   |  
17-Nov | 1:30:00 PM | 2:45:00 PM | 1.25 | Other (Describe in Notes) | Conference
18-Nov | 10:00:00 AM | 12:00:00 PM | 2.00 | Other (Describe in Notes) | Conference
19-Nov | 7:30:00 PM | 9:00:00 PM | 1.50 | Club Meetings/Activities | ASM #3
20-Nov |   |   | 0.00 |   |  
21-Nov |   |   | 0.00 |   |  
22-Nov |   |   | 0.00 |   |  
23-Nov |   |   | 0.00 |   |  
24-Nov |   |   | 0.00 |   |  
25-Nov |   |   | 0.00 |   |  
26-Nov | 2:00:00 PM | 2:45:00 PM | 0.75 | Special Project (Describe in Notes) | Picked out the rest of the components and changed USB to UART connector back to a more advanced one (CTS != DTR)
27-Nov |   |   | 0.00 |   |  
28-Nov |   |   | 0.00 |   |  
29-Nov |   |   | 0.00 |   |  
30-Nov |   |   | 0.00 |   |  
  |   |   | 0.00 |   |  
  |   |   | 0.00 |   |  
  |   |   | 0.00 |   |  
  |   |   | 0.00 |   |  
  |   |   | 0.00 |   |  
  |   |   | 0.00 |   |  
  |   |   | 0.00 |   |  
  |   |   | 0.00 |   |  
  |   |   | 0.00 |   |  
  |   |   | 0.00 |   |  
  |   |   | 0.00 |   |  
  |   |   | 0.00 |   |  
  |   |   | 0.00 |   |  
  |   |   | 0.00 |   |  
  |   |   | 0.00 |   |  
  |   |   | 0.00 |   |  
  |   | Total: | 16.25 |   |  

## December 2023

Date: | Time In: | Time Out: | Hours: | Activity: | Notes:
-- | -- | -- | -- | -- | --
1-Dec |   |   | 0.00 |   |  
2-Dec |   |   | 0.00 |   |  
3-Dec |   |   | 0.00 |   |  
4-Dec |   |   | 0.00 |   |  
5-Dec |   |   | 0.00 |   |  
6-Dec |   |   | 0.00 |   |  
7-Dec |   |   | 0.00 |   |  
8-Dec |   |   | 0.00 |   |  
9-Dec |   |   | 0.00 |   |  
10-Dec |   |   | 0.00 |   |  
11-Dec |   |   | 0.00 |   |  
12-Dec |   |   | 0.00 |   |  
13-Dec |   |   | 0.00 |   |  
14-Dec |   |   | 0.00 |   |  
15-Dec |   |   | 0.00 |   |  
16-Dec |   |   | 0.00 |   |  
17-Dec |   |   | 0.00 |   |  
18-Dec |   |   | 0.00 |   |  
19-Dec |   |   | 0.00 |   |  
20-Dec |   |   | 0.00 |   |  
21-Dec |   |   | 0.00 |   |  
22-Dec |   |   | 0.00 |   |  
23-Dec |   |   | 0.00 |   |  
24-Dec |   |   | 0.00 |   |  
25-Dec |   |   | 0.00 |   |  
26-Dec |   |   | 0.00 |   |  
27-Dec |   |   | 0.00 |   |  
28-Dec | 10:45:00 AM | 12:15:00 PM | 1.50 | Reflection Journal | Reflection Journal for Fall 2023 Semester
29-Dec |   |   | 0.00 |   |  
30-Dec |   |   | 0.00 |   |  
  |   |   | 0.00 |   |  
  |   |   | 0.00 |   |  
  |   |   | 0.00 |   |  
  |   |   | 0.00 |   |  
  |   |   | 0.00 |   |  
  |   |   | 0.00 |   |  
  |   |   | 0.00 |   |  
  |   |   | 0.00 |   |  
  |   |   | 0.00 |   |  
  |   |   | 0.00 |   |  
  |   |   | 0.00 |   |  
  |   |   | 0.00 |   |  
  |   |   | 0.00 |   |  
  |   |   | 0.00 |   |  
  |   |   | 0.00 |   |  
  |   |   | 0.00 |   |  
  |   | Total: | 1.50 |   |
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

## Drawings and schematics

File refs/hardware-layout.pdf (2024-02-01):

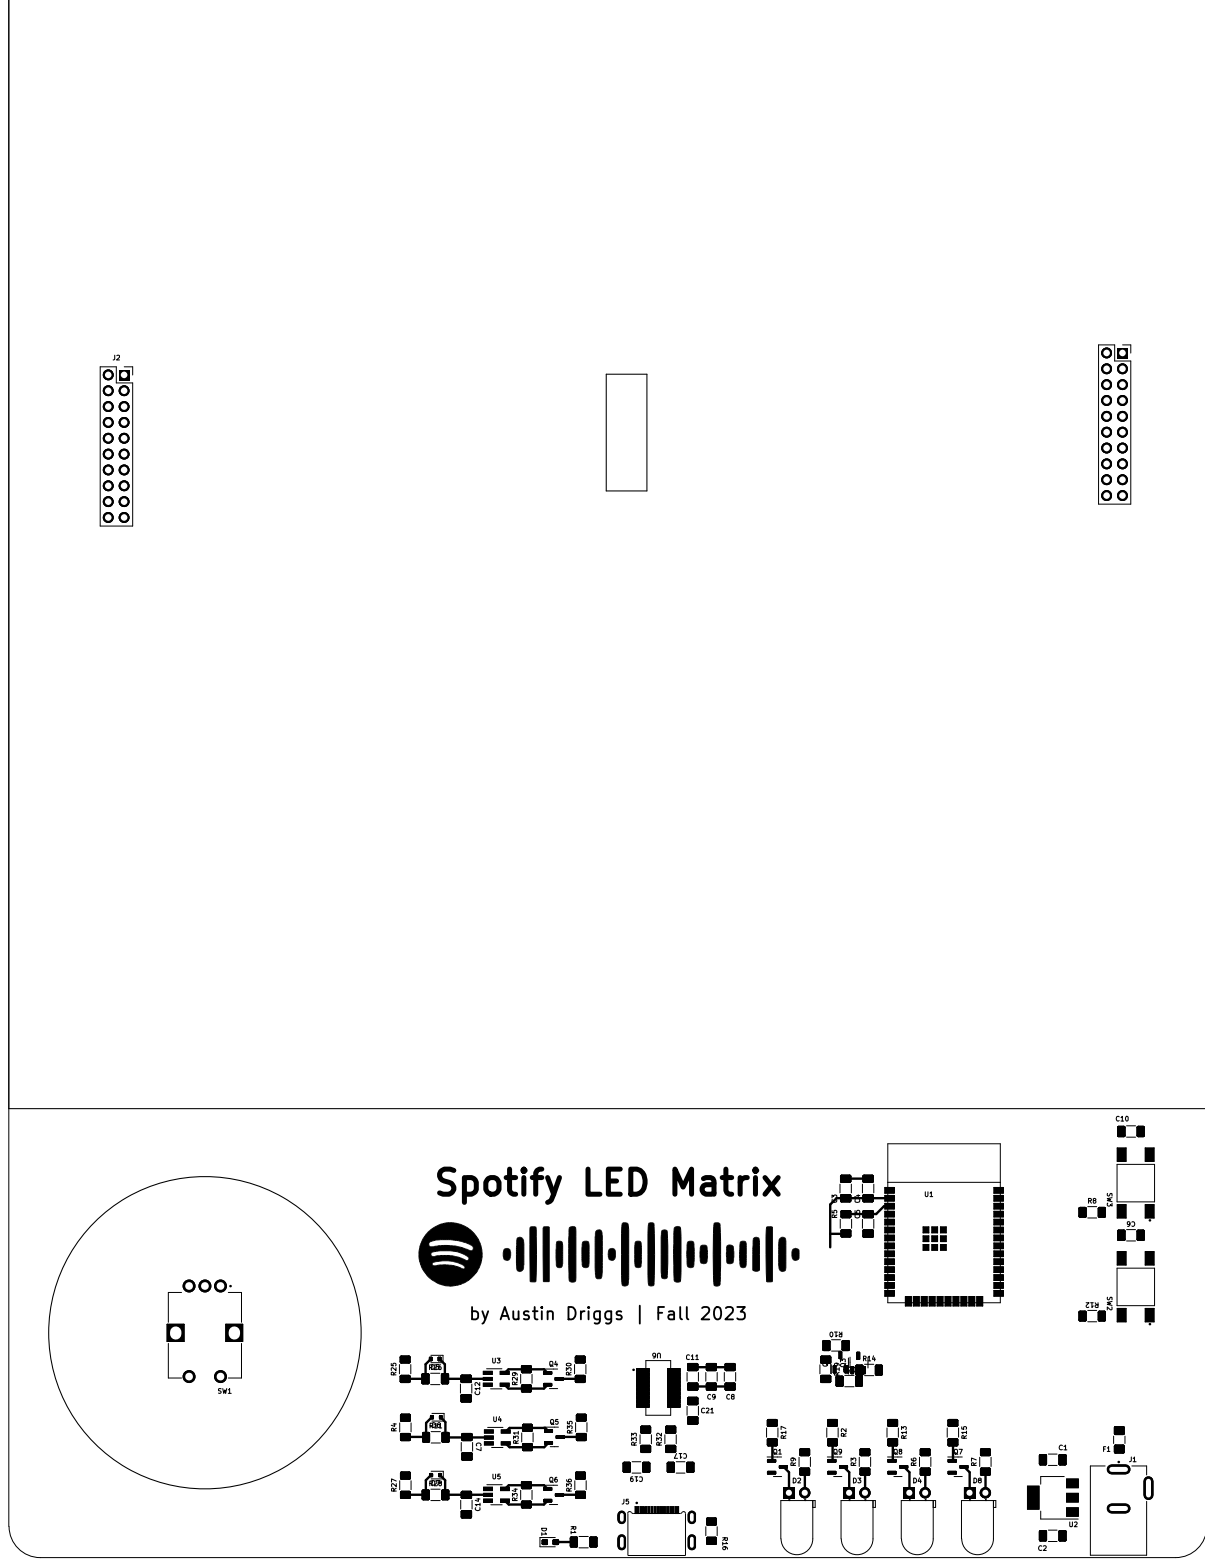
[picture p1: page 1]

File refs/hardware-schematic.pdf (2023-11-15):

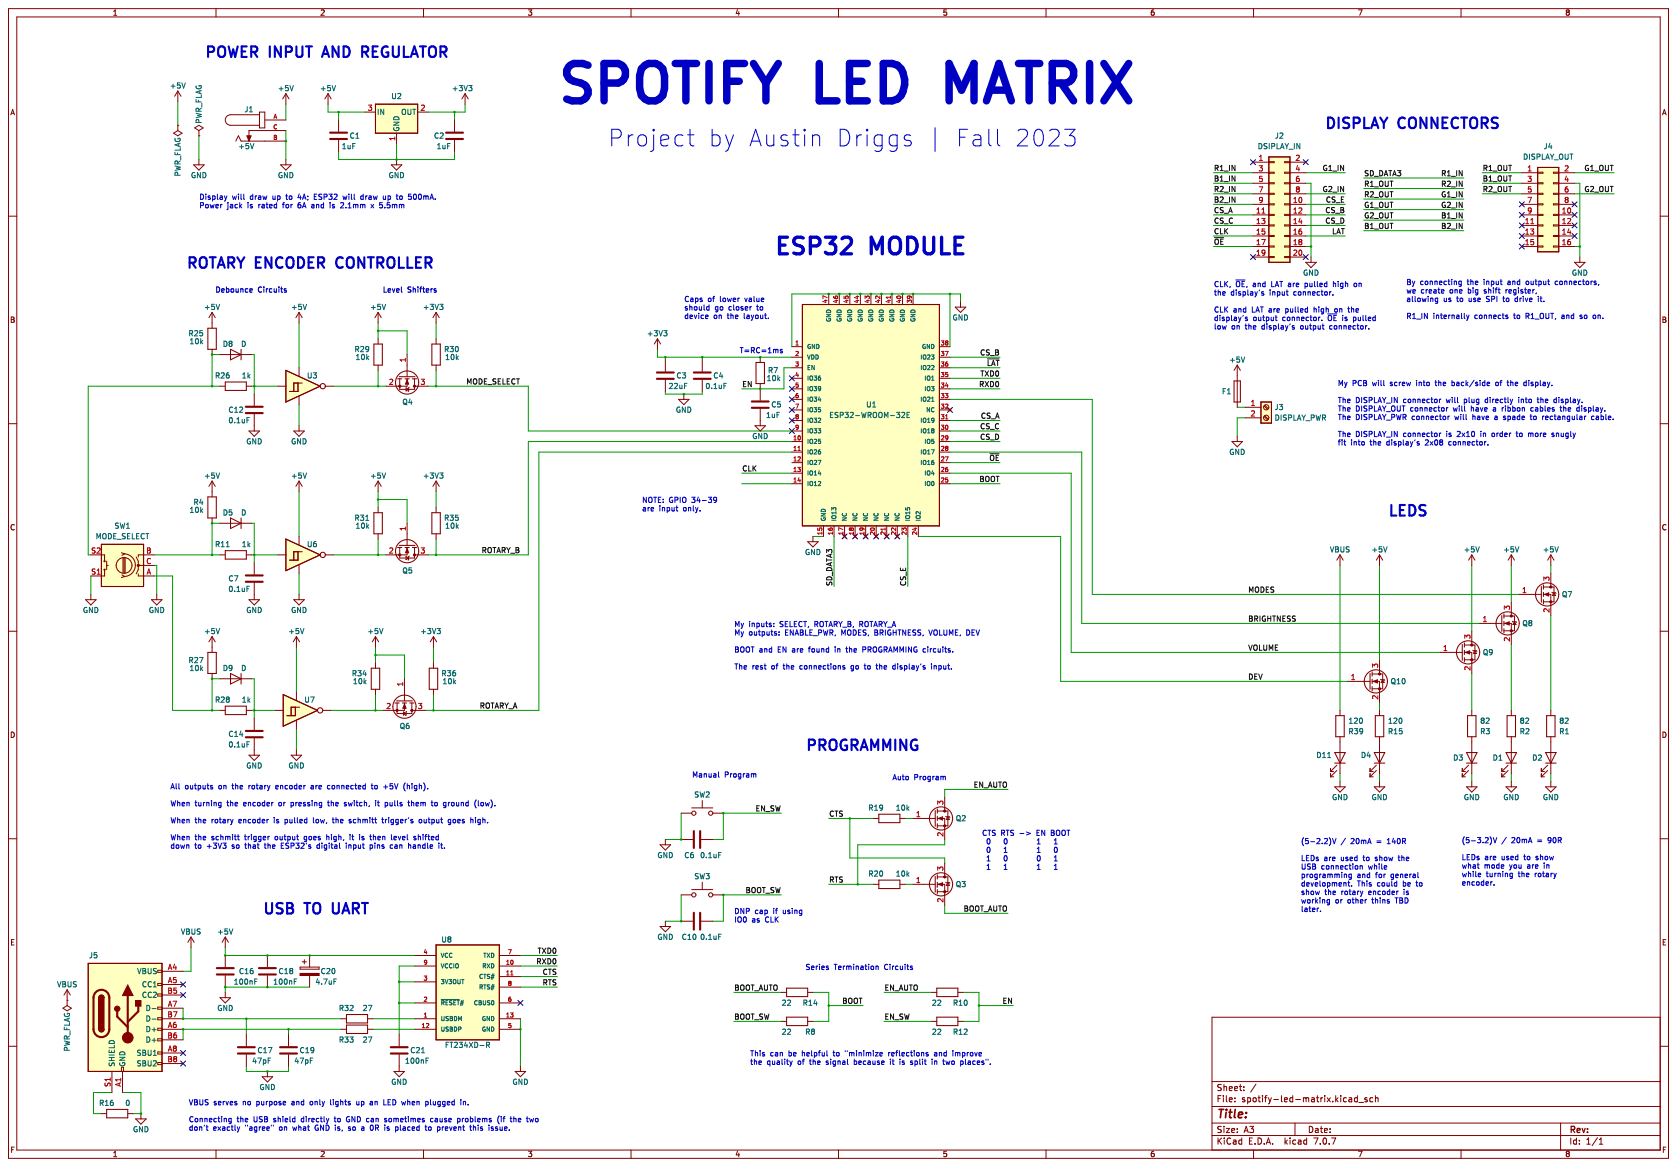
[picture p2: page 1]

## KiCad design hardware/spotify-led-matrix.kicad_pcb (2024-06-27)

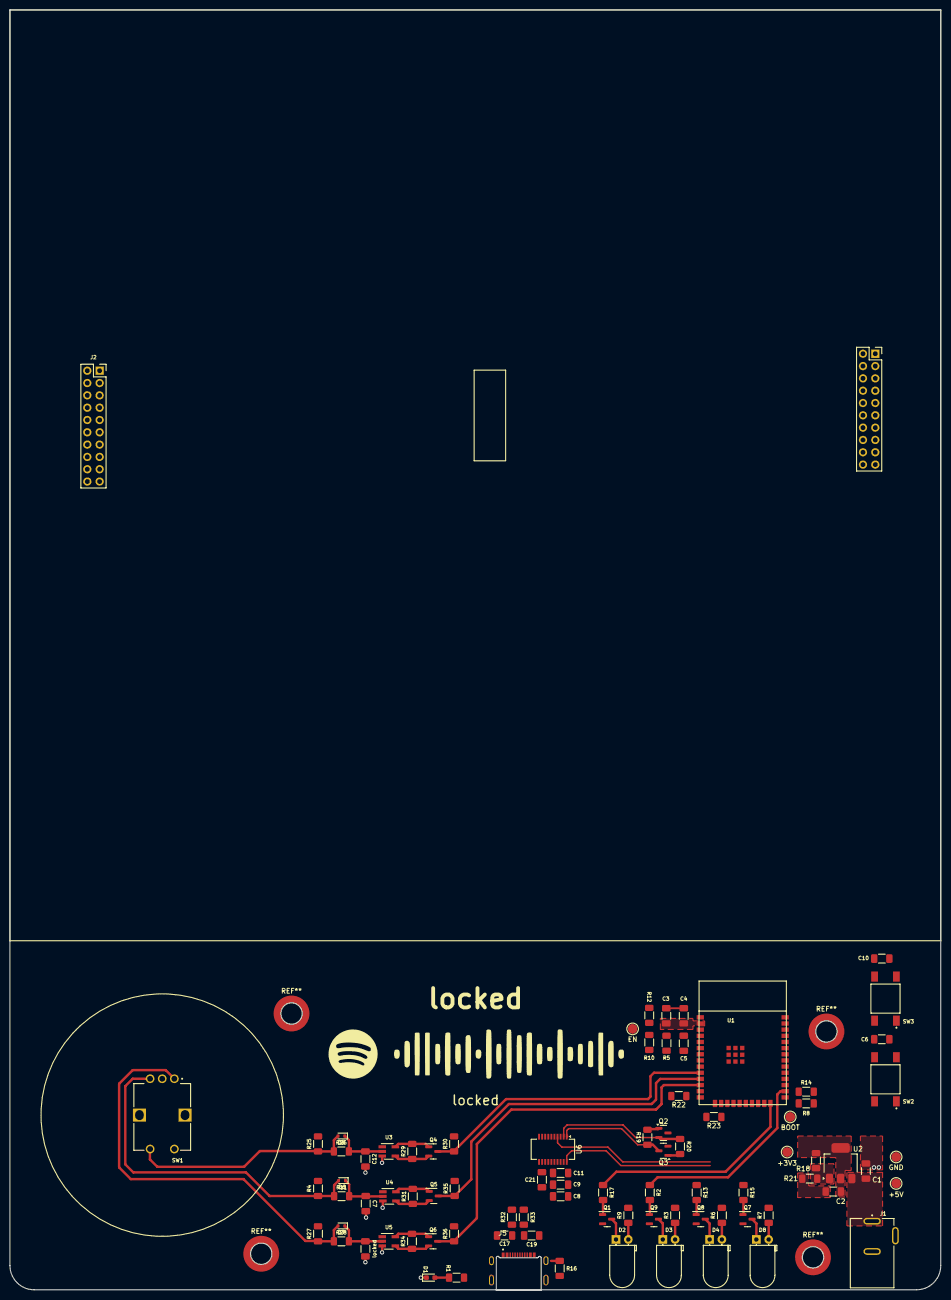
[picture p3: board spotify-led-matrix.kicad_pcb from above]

Board: 2 copper layers, 192.0 x 264.0 mm, 86 parts (0 on the bottom side), 68 nets.

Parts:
C1, C2: 10uF; C_1206_3216Metric_Pad1.33x1.80mm_HandSolder
C3: 22uF; C_1206_3216Metric_Pad1.33x1.80mm_HandSolder
C4, C6, C7, C10, C12: 0.1uF; C_1206_3216Metric_Pad1.33x1.80mm_HandSolder
C5: 1uF; C_1206_3216Metric_Pad1.33x1.80mm_HandSolder
C8: 4.7uF; C_1206_3216Metric_Pad1.33x1.80mm_HandSolder
C9, C11, C21: 100nF; C_1206_3216Metric_Pad1.33x1.80mm_HandSolder
C17, C19: 47pF; C_1206_3216Metric_Pad1.33x1.80mm_HandSolder
D1: USB; LED_0603_1608Metric_Pad1.05x0.95mm_HandSolder
D2: DEV; LED_D5.0mm_Horizontal_O1.27mm_Z9.0mm
D3: VOLUME; LED_D5.0mm_Horizontal_O1.27mm_Z9.0mm
D4: BRIGHTNESS; LED_D5.0mm_Horizontal_O1.27mm_Z9.0mm
D5, D6, D7: D; D_SOD-523
D8: MODES; LED_D5.0mm_Horizontal_O1.27mm_Z9.0mm
J1: +5V; 54-00166
J2: DISPLAY_IN; PinSocket_2x10_P2.54mm_Vertical
J4: DISPLAY_OUT; PinSocket_2x10_P2.54mm_Vertical
J5: USB_C_Receptacle_USB2.0; MOLEX_2169900003
Q1, Q4, Q5, Q6, Q7, Q8, Q9: IRLML6244TRPBF; SOT-23
Q2, Q3: SS8050-G; SOT-23
R1, R9: 120; R_1206_3216Metric_Pad1.30x1.75mm_HandSolder
R2, R11, R13, R15, R17, R26, R28: 1k; R_1206_3216Metric_Pad1.30x1.75mm_HandSolder
R3, R6, R7: 82; R_1206_3216Metric_Pad1.30x1.75mm_HandSolder
R4, R5, R19, R20, R25, R27, R29, R30, R31, R34, R35, R36: 10k; R_1206_3216Metric_Pad1.30x1.75mm_HandSolder
R8, R10, R12, R14, R22, R23: 22; R_1206_3216Metric_Pad1.30x1.75mm_HandSolder
R16: 0; R_1206_3216Metric_Pad1.30x1.75mm_HandSolder
R18, R21: R_1206_3216Metric_Pad1.30x1.75mm_HandSolder
R32, R33: 27; R_1206_3216Metric_Pad1.30x1.75mm_HandSolder
SW1: MODE_SELECT; CUI_ACZ11BR1E-20FD1-20C
SW2: EN; SW_TL3301DF160QG
SW3: BOOT; SW_TL3301DF160QG
TP1: +5V; TestPoint_Pad_D2.0mm
TP2: GND; TestPoint_Pad_D2.0mm
TP3: +3V3; TestPoint_Pad_D2.0mm
TP4: BOOT; TestPoint_Pad_D2.0mm
TP5: EN; TestPoint_Pad_D2.0mm
U1: ESP32-WROOM-32E
U2: NCP1117-ADJ; SOT-223-3_TabPin2
U3, U4, U5: MC74HC1G14DTT1G; SOT-23-5_HandSoldering
U6: FT231XS-R; SSOP-20_3.9x8.7mm_P0.635mm
locked: 0.1uF; C_1206_3216Metric_Pad1.33x1.80mm_HandSolder

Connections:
+3V3: C2.1, C3.1, C4.1, R5.1, R18.2, R30.2, R35.2, R36.2, TP3.1, U1.2 (VDD), U2.2 (VO)
+5V: C1.1, C8.1, C9.1, C11.1, J1.A, Q4.1 (G), Q5.1 (G), Q6.1 (G), R3.2, R4.2, R6.2, R7.2, R9.2, R25.2, R27.2, R29.2, R31.2, R34.2, TP1.1, U2.3 (VI), U3.5 (VCC), U4.5 (VCC), U5.5 (VCC), U6.15 (VCC)
/B1_IN: J2.5 (B1), J4.8 (G2)
/B2_IN: J2.9 (B2), J4.5 (B1)
/BOOT: R8.1, R14.1, TP4.1, U1.25 (IO0)
/BOOT_AUTO: Q3.2 (S), R8.2
/BOOT_SW: C10.1, R14.2, SW3.2
/BRIGHTNESS: R13.1, U1.28 (IO17)
/BUTTON: Q4.3 (D), R30.1, U1.10 (IO25)
/CS_A: J2.11 (A), U1.31 (IO19)
/CS_B: J2.12 (B), U1.37 (IO23)
/CS_C: J2.13 (C), U1.30 (IO18)
/CS_D: J2.14 (D), U1.29 (IO5)
/CS_E: J2.10 (E), U1.23 (IO15)
/D+: C17.1, J5.A6 (D+), J5.B6 (D+), R32.1
/D-: C19.1, J5.A7 (D-), J5.B7 (D-), R33.1
/DEV: R17.1, U1.24 (IO2)
/DTR: Q3.3 (D), R19.1, U6.1 (~DTR)
/EN: C5.1, R5.2, R10.1, R12.1, TP5.1, U1.3 (EN)
/EN_AUTO: Q2.3 (D), R12.2
/EN_SW: C6.1, R10.2, SW2.2
/G1_IN: J2.4 (G1), J4.7 (R2)
/G2_IN: J2.8 (G2), J4.4 (G1)
/MODES: R15.1, U1.33 (IO21)
/R2_IN: J2.7 (R2), J4.3 (R1)
/ROTARY_A: Q6.3 (D), R36.1, U1.12 (IO27)
/ROTARY_B: Q5.3 (D), R35.1, U1.11 (IO26)
/RTS: Q2.2 (S), R20.1, U6.2 (~RTS)
/RXD0: U1.34 (IO3), U6.4 (RXD)
/SPI_CLK: J2.15 (CLK), R22.2
/SPI_SDA: J2.3 (R1), R23.2
/TXD0: U1.35 (IO1), U6.20 (TXD)
/USBD+: R32.2, U6.11 (USBDP)
/USBD-: R33.2, U6.12 (USBDM)
/VOLUME: R2.1, U1.26 (IO4)
/~LAT: J2.16 (LAT), U1.36 (IO22)
/~OE: J2.17 (~OE), U1.27 (IO16)
GND: C1.2, C2.2, C3.2, C4.2, C5.2, C6.2, C7.2, C8.2, C9.2, C10.2, C11.2, C12.2, C17.2, C19.2, C21.2, D1.1 (K), J1.B, J1.C, J2.6 (GND), J2.18 (GND), J4.6 (GND), J4.18 (GND), J5.A1 (GND), J5.B1 (GND), Q1.2 (S), Q7.2 (S), Q8.2 (S), Q9.2 (S), R16.2, R21.1, SW1.C, SW1.S1, SW2.1, SW3.1, TP2.1, U1.1 (GND), U1.15 (GND), U1.38 (GND), U1.39 (GND), U1.40 (GND), U1.41 (GND), U1.42 (GND), U1.43 (GND), U1.44 (GND), U1.45 (GND), U1.46 (GND), U1.47 (GND), U3.3 (GND), U4.3 (GND), U5.3 (GND), U6.5 (~RI), U6.6 (GND), U6.8 (~DCD), U6.16 (GND), locked.2
unnamed: D1.2 (A), R1.1
unnamed: D2.2 (A), R9.1
unnamed: D2.1 (K), Q1.3 (D)
unnamed: D3.2 (A), R3.1
unnamed: D3.1 (K), Q9.3 (D)
unnamed: D4.2 (A), R6.1
unnamed: D4.1 (K), Q8.3 (D)
unnamed: D5.2 (A), R25.1, R26.1, SW1.S2
unnamed: C12.1, D5.1 (K), R26.2, U3.2
unnamed: D6.2 (A), R4.1, R11.1, SW1.B
unnamed: C7.1, D6.1 (K), R11.2, U4.2
unnamed: D7.2 (A), R27.1, R28.1, SW1.A
unnamed: D7.1 (K), R28.2, U5.2, locked.1
unnamed: D8.2 (A), R7.1
unnamed: D8.1 (K), Q7.3 (D)
unnamed: J5.S1 (SHIELD), R16.1
unnamed: Q1.1 (G), R17.2
unnamed: Q2.1 (G), R19.2
unnamed: Q3.1 (G), R20.2
unnamed: Q4.2 (S), R29.1, U3.4
unnamed: Q5.2 (S), R31.1, U4.4
unnamed: Q6.2 (S), R34.1, U5.4
unnamed: Q7.1 (G), R15.2
unnamed: Q8.1 (G), R13.2
unnamed: Q9.1 (G), R2.2
unnamed: R23.1, U1.16 (IO13)
unnamed: R22.1, U1.13 (IO14)
unnamed: R18.1, R21.2, U2.1 (ADJ)
unnamed: C21.1, U6.3 (VCCIO), U6.13 (3V3OUT), U6.14 (~RESET)
VBUS: J5.A4 (VBUS), J5.B4 (VBUS), R1.2

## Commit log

2023-10-04 Added KiCad files for initial circuit design.
    [ESP32-WROOM-32E.step, spotify-led-matrix.kicad_pcb, spotify-led-matrix.kicad_sch]
2023-10-04 Added pdf of schematic
2023-10-14 Added some connections for SPI communication to display
    [spotify-led-matrix.kicad_sch]
2023-10-14 Saved PDF to reflect changes to schematic
2023-11-01 Only updated PDF to show the current schematic.
    [spotify-led-matrix.kicad_pcb, spotify-led-matrix.kicad_sch]
2023-11-10 Replaced USB to UART converter and updated schematic format
    [BAT760-7.step, CP2102N-A01-GQFN28.step, EVE-YBCAJ008B.stp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]
2023-11-13 Only updated schematic.pdf to show updated circuit 231113.
2023-11-14 Re-updated schematic.pdf to show updated circuit 231113.
2023-11-15 Finished schematic and picked out most parts
    [spotify-led-matrix.kicad_pcb, spotify-led-matrix.kicad_sch]
2023-11-15 Updated schematic
    [spotify-led-matrix.kicad_sch]
2023-11-15 Working out gitignore issues.
    [spotify-led-matrix.kicad_pcb, spotify-led-matrix.kicad_sch]
2023-11-15 Updated gitignore
    [spotify-led-matrix.kicad_pcb, spotify-led-matrix.kicad_sch]
2023-11-15 Cleaned up file organization
    [BAT760-7.step, spotify-led-matrix.kicad_sch]
2023-12-02 Cleaned up a lot and started pcb layout
    [FT231XS-R.step, FT234XD-R.step, spotify-led-matrix.kicad_pcb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]
2024-01-09 Reorganized files again: Wanted to push to backup everything.
    [spotify-led-matrix.kicad_pcb, spotify-led-matrix.kicad_sch]
2024-01-31 worked on the layout
    [spotify-led-matrix.kicad_pcb, spotify-led-matrix.kicad_sch]
2024-01-31 more layout stuff
    [spotify-led-matrix.kicad_pcb, spotify-led-matrix.kicad_sch]
2024-01-31 locked layouts
    [spotify-led-matrix.kicad_pcb]
2024-01-31 locked more
    [spotify-led-matrix.kicad_pcb]
2024-01-31 added step files
    [spotify-led-matrix.kicad_pcb]
2024-02-01 layout stuff and .gitignore update
    [spotify-led-matrix.kicad_sch]
2024-02-01 added hardware-layout.pdf and started power supply swap
2024-04-06 reformatted schematic and changed parts: - added new voltage regulator: 1117 adjustable (jellybean) - added temp/volt/cur sensor LTC2990 - changed usb to uart IC to SSOP20 footprint - created and add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
    [spotify-led-matrix.kicad_pcb, spotify-led-matrix.kicad_sch]
2024-04-17 lots of changes: working on finalizing everything!
    [spotify-led-matrix.kicad_pcb, spotify-led-matrix.kicad_sch]
